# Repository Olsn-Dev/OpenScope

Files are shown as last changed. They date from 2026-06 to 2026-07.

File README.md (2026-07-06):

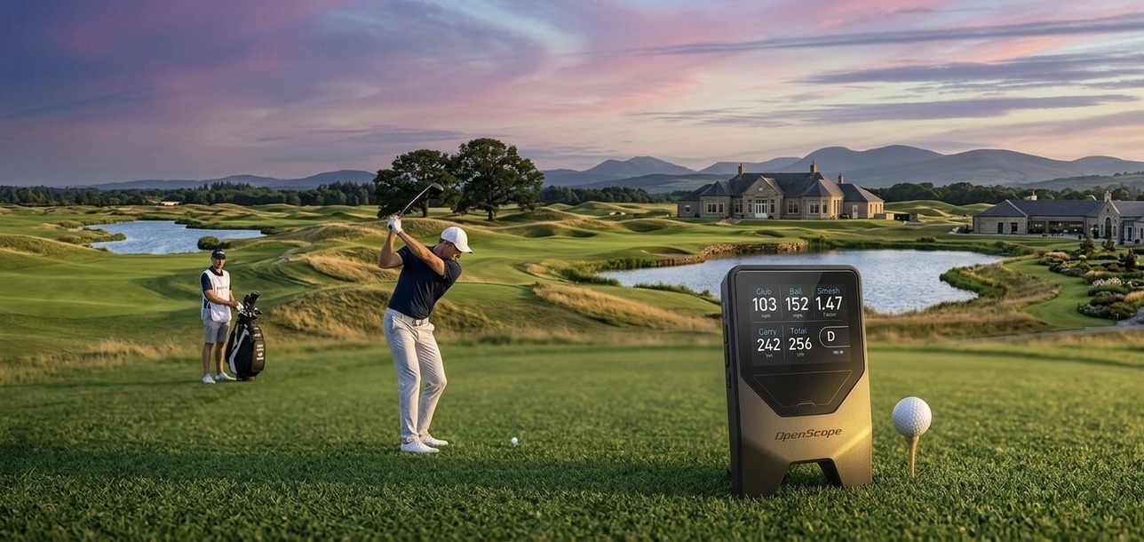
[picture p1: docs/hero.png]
OpenScope


# OpenScope — DIY Golf Launch Monitor

A radar-based golf launch monitor built around a **single** 24 GHz Doppler
radar module and an ESP32, modelled on the commercial single-Doppler
[Shot Scope LM1](https://shotscope.com/). Measures ball speed, club speed
and smash factor directly, and estimates carry and total distance.
Battery-powered, no phone required.

## What it measures (and what it can't)

A single Doppler sensor sees only speed along its line of sight. That is
enough for the core launch-monitor metrics, but **not** for launch angle,
spin, or shot direction — those need extra sensors. OpenScope is honest
about the difference:

| Metric | Source |
|---|---|
| Ball speed | **Measured** — post-impact Doppler peak |
| Club head speed | **Measured** — pre-impact clubhead Doppler peak |
| Smash factor | **Measured** — ball speed ÷ club speed |
| Carry distance | **Modeled** — from ball speed + per-club ballistic factor |
| Total distance | **Modeled** — carry + per-club rollout factor |
| Launch angle | **Not available** — needs a second/elevated sensor |
| Spin (back/side) | **Not available** — out of reach for plain Doppler |
| Side angle / dispersion | **Not available** — needs ≥2 sensors |

Other features:

- Units in km/h · m or mph · yds
- 3.5" color TFT display (ILI9488) + 3-button navigation
- Per-club statistics (avg, best carry) stored in flash
- Deep sleep with one-button wake
- Calibration mode with live FFT spectrum

## Technology

One **CDM324 24 GHz K-band Doppler radar** feeds into an LM358
preamplifier. The ESP32 samples the IF signal at 40 kHz and runs a
1024-point Hamming-windowed FFT (~25 ms window). Within that window the
spectrum can hold two peaks — the slower **clubhead** (pre-impact) and the
faster **ball** (post-impact):

```
CDM324 emits a continuous 24.125 GHz tone. A moving object Doppler-shifts
the reflection:

  f_d = 2 · v · f_c / c
  v [km/h] = f_d [Hz] × 0.022384

The unit sits in line with the shot, so the radar sees the true
line-of-sight speed — no angle correction is needed:

  ball speed  = (higher peak) × 0.022384 km/h
  club speed  = (lower  peak) × 0.022384 km/h
  smash       = ball speed ÷ club speed
  carry       = ball speed × club.carry_f      (modeled)
  total       = carry × (1 + club.roll_f)      (modeled)
```

## Project Phases

| Phase | Description | Status |
|---|---|---|
| 1 | Hardware & wiring | 🟡 In progress (v0.7) |
| 2 | Software & calibration | 🟡 In progress (v0.7) |
| 3 | Physical prototyping | 🔲 Not started |
| 4 | Housing & battery optimization | 🔲 Not started |
| 5 | Testing & validation | 🔲 Not started |

## Repository Structure

```
golf-launch-monitor/
├── src/
│   ├── config.h          # pins, FFT/Doppler constants, layout
│   ├── radar.cpp/.h      # ADC sampling, FFT, peak detection
│   ├── clubs.cpp/.h      # club table + per-club stats
│   ├── buttons.cpp/.h    # debounced 3-button input (UP / DOWN / OK)
│   ├── display.cpp/.h    # all TFT drawing, themes
│   ├── storage.cpp/.h    # NVS persistence
│   └── main.cpp          # button-driven UI state machine, sleep, main loop
├── test/
│   └── test_speed_from_fft/  # native smoke test (pio test -e native)
├── docs/
│   ├── bom.md            # Bill of materials with part numbers
│   ├── wiring.md         # Wiring diagram, radar placement
│   └── openscope-ui.png  # UI mockup
├── platformio.ini        # PlatformIO build configuration
└── README.md
```

## Quick Start

1. Order components — see [docs/bom.md](docs/bom.md)
2. Wire up the circuit — see [docs/wiring.md](docs/wiring.md)
3. Place the unit ~1.4 m behind the ball, facing the target (see below)
4. Install [PlatformIO](https://platformio.org/)
5. Clone this repo and open in VS Code
6. Build & upload: `pio run --target upload`
7. Calibrate — see below

## Radar Placement

Place the unit on the ground **~1.4 m (4–5 ft) behind the ball**, in line
with the hitting direction, with the sensor/screen facing the target —
the same geometry the Shot Scope LM1 uses. The ball flies *away* from the
unit; Doppler measures a receding object identically to an approaching one.

```
Top view:

 [Unit] ──── ~1.4 m ────► ●  →  →  →  target
  (on ground,            ball
   facing target)
```

- One CDM324 module, flat on the ground, boresight pointing at the target.
- Aim it down the intended shot line through the ball.
- Keep it static — vibration adds noise.

> **Speed-training tip:** to read swing speed alone, place the unit ~2.1 m
> behind the golfer instead.

## Controls

**Three buttons: UP, DOWN, OK.** UP/DOWN move the list highlight (auto-repeat
when held); OK activates the highlighted row. Holding **OK 1.5 s** powers off
from anywhere; pressing OK wakes the unit.

| Screen | UP / DOWN | OK |
|---|---|----|
| Main menu | Move highlight | Open **Start Session** / **Shot History** / **Settings** / **Shut Down** |
| Mode select | Move highlight | Open **Practice Range** / **On Course** / **Speed Training** / **Back** |
| Shot history | Page newer / older (last 50 shots) | Back |
| Session (Advanced) | Change club | Open the **session menu** |
| Session (Large Digit) | Cycle metric (club → ball → smash → carry → total) | Open the **session menu** |
| Session menu | Move highlight | **Resume** / **Change Club** / **Layout** / **Settings** / **End Session** |
| Result | Any button dismisses | Any button dismisses |
| Club picker | Move highlight (list follows) | Select club |
| Settings | Move highlight | Toggle / open the highlighted row |
| Calibration | Threshold **+10** / **−10** | **Save** + exit |

## Display Layout

Navigation is **Main menu → Mode select → Session**, modelled on the Shot
Scope LM1. A session shows shot data in one of two layouts (toggled in the
session menu or Settings), in either a **Black** (white labels) or **Blue**
(cyan labels) theme — both set in Settings.

### Advanced — 3×2 tile grid

```
┌──────────┬──────────┬──────────┐
│  CLUB    │  BALL    │  SMASH   │
│  98      │  152     │  1.55    │
│  km/h    │  km/h    │          │
├──────────┼──────────┼──────────┤
│  CARRY   │  TOTAL   │ ┌──────┐ │
│  187     │  209     │ │  7I  │ │  ← UP/DOWN change the club
│  m       │  m       │ └──────┘ │
├──────────┴──────────┴──────────┤
│ UP/DN: CLUB  SWING WHEN READY  OK: MENU │
└────────────────────────────────┘
```

The five tiles are the five single-Doppler metrics: **club speed**, **ball
speed**, **smash factor** (measured) plus **carry** and **total** (modeled).

- **Smash** tile turns green when a club peak was found; `--` (dimmed) if only
  the ball was detected, in which case Club and Smash both read `--`.

### Large Digit — one metric, full size

```
┌─────────────────────────────────┐
│         Total Distance          │
│                      ┌──────┐   │
│         209          │  7I  │   │
│          m           └──────┘   │
│                                 │
│ UP/DN: METRIC  SWING WHEN READY  OK: MENU │
└─────────────────────────────────┘
```

Toggle Advanced ⇄ Large Digit from the session menu (OK) or Settings; in
Large Digit, **UP/DOWN** cycle club speed → ball speed → smash → carry →
total.

### Speed Training

A single huge **swing-speed** number (the dominant Doppler peak) for swing-speed
practice — no club selection or distance modelling.

### Settings screen

Reached from the main menu, or via the session menu during a session.
UP/DOWN move the highlight; OK toggles or opens the highlighted row.

```
┌─────────────────────────────────────────────┐
│                 Settings     OK: toggle/open  │
├─────────────────────────────────────────────┤
│▌ Units                              Kmh/m   │
│▌ Color                              Black   │
│▌ Layout                          Advanced   │
│▌ Reset Stats                          7I    │
│▌ Clear History                         ►    │
│▌ Radar Cal.                            ►    │
│▌ Back                                  ◄    │
└─────────────────────────────────────────────┘
```

| Item | Action |
|---|---|
| Units | Toggle **Kmh/m** ↔ **Mph/Yds** |
| Color | **Black** ↔ **Blue** theme |
| Layout | **Advanced** ↔ **Large Digit** |
| Reset Stats | Clears avg/best for the active club |
| Clear History | Wipes the 50-shot log |
| Radar Cal. | Opens the detection-threshold calibration screen |
| Back | Save and return |

## Calibration

The detection threshold tells the firmware what signal level counts as
a real shot vs. background noise. It is saved to flash.

### Enter calibration

From the main menu → **Settings** → **Radar Cal.**

```
┌──────────────────────────────────────────────────────┐
│  CALIBRATION MODE         UP/DOWN: adjust   OK: save  │
├──────────────────────────────────────────────────────┤
│  [live FFT spectrum — teal bars below threshold,      │
│   red bars above — yellow line = threshold]           │
├───────────────┬───────────────┬──────────────────────┤
│ NOISE FLOOR   │ PEAK MAG      │ MAX SEEN             │
│ 14.2          │ 14.2          │ 14.2                 │
├───────────────┴───────────────┴──────────────────────┤
│ PEAK 0 Hz = 0.0 km/h                                  │
│ THRESHOLD 80         SUGGESTED 58                     │
├───────────────┬───────────────┬──────────────────────┤
│  DOWN: −10    │   OK: SAVE    │    UP: +10           │
└───────────────┴───────────────┴──────────────────────┘
```

### Steps

1. Leave the device still for ~30 s. Note **NOISE FLOOR** (typically 8–20).
2. Take a full practice swing. Note **MAX SEEN** (typically 200–600).
3. Press **DOWN** / **UP** (hold to sweep) to move the yellow threshold line
   between noise floor and MAX SEEN. The **SUGGESTED** value (`noise × 4`)
   is a good starting point.
4. Press **OK** to save and return.

| Measurement | Typical value |
|---|---|
| Noise floor | 10–20 |
| Shot peak | 200–600 |
| Good threshold | 60–100 |

> Raise the threshold if you get false triggers. Lower it if real shots
> are not detected.

## How it works

The ESP32 samples the radar IF at 40 kHz and runs a 1024-point Hamming FFT
(~25 ms window). Within each frame up to two peaks are searched, at least
`MIN_PEAK_SEP_HZ` apart: if their ratio looks like a plausible ball/club
pair, the **lower** frequency is the clubhead and the **higher** is the
ball; otherwise only ball speed is reported. Parabolic interpolation gives
sub-bin frequency accuracy. Each peak is converted to speed with
`HZ_TO_KMH`; smash is the ratio, and carry/total are modeled per club.

Because the unit is aligned with the shot line, the radar reads true
line-of-sight speed — there is no V-formation, no triangulation, and no
angle correction. See [the source](src/radar.cpp) for the signal chain and
[`test/`](test/) for a host-side smoke test of the speed-from-FFT path
(`pio test -e native`).

## UI Mockup

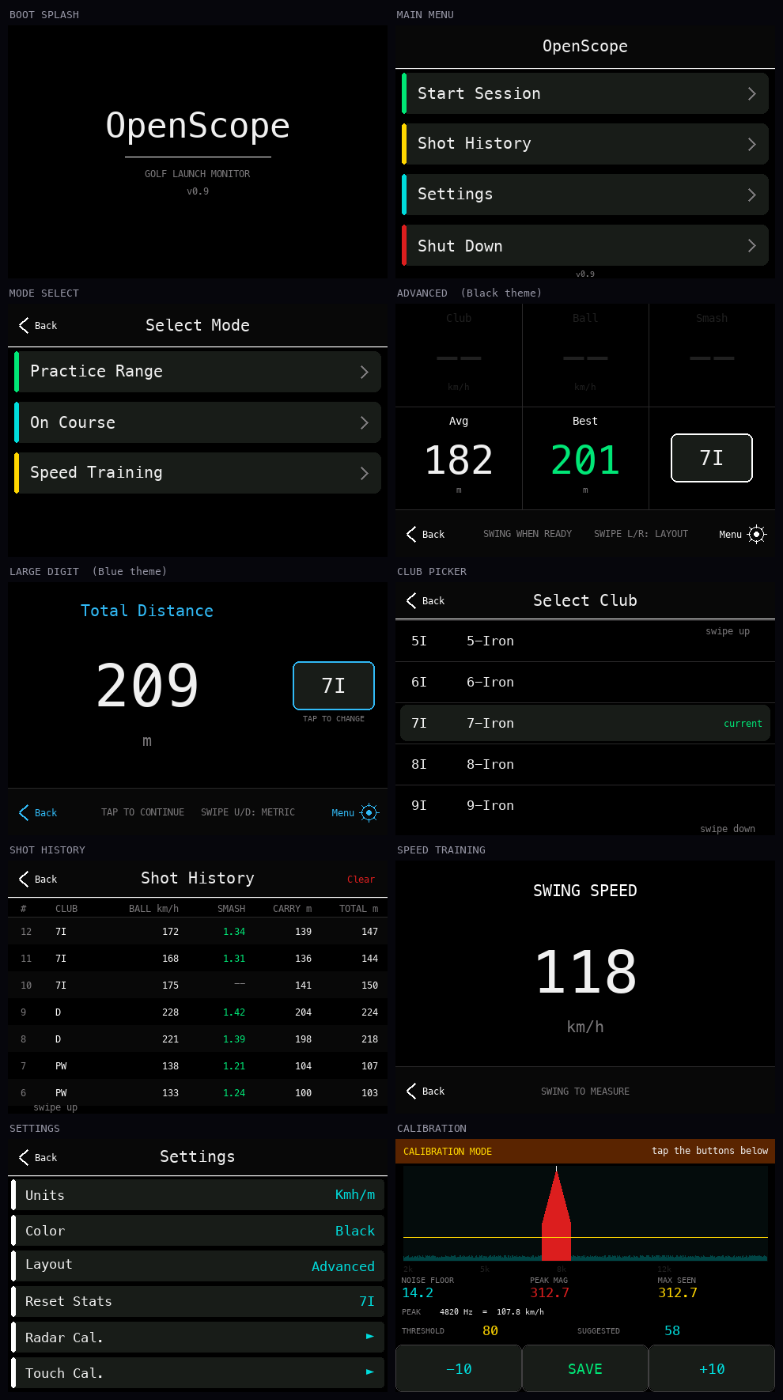
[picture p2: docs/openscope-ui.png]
OpenScope UI — ten screens: boot splash, menu, mode select, Advanced & Large Digit layouts, club picker, shot history, speed training, settings, calibration


## License

MIT

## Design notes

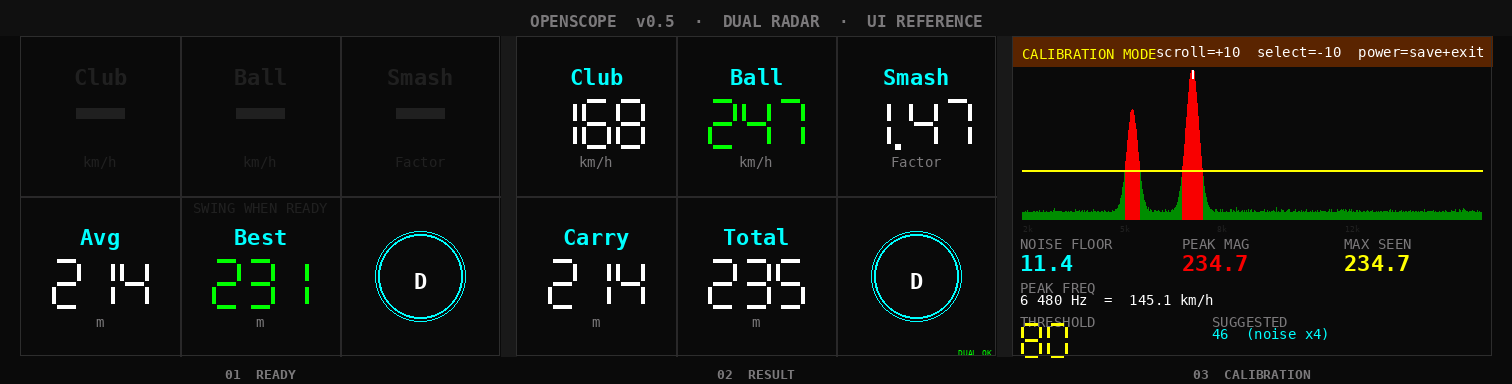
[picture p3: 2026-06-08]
docs/openscope-ui-dual.png

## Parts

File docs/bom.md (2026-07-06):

# Bill of Materials — OpenScope v0.8 (single radar)

All components from AliExpress unless noted. Prices approximate (SEK).

---

## Main Components

| # | Component | Search / Part number | Qty | ~Price (SEK) |
|---|---|---|-----|---|
| 1 | ESP32 dev board with 18650 battery holder | `ESP32 18650 battery holder board` | 1 | 160 |
| 2 | 18650 Li-Ion battery, 3000 mAh, protected | `18650 3000mAh protected battery` | 1 | 60 |
| 3 | CDM324 24 GHz Doppler radar module | AliExpress: `4000332661554` | 1 | 20 |
| 4 | LM358 preamp — bare DIP-8 IC **or** pre-built HW-164 ×100 module | `LM358 op amp DIP8` / `LM358 signal amplifier module` | 1 | 7 |
| 5 | 3.5" TFT display, SPI, ILI9488, 480×320 (touch panel not needed) | `3.5 inch SPI TFT ILI9488 480x320` | 1 | 120 |
| 6 | Tactile push button, 6×6 mm, PCB mount (UP / DOWN / OK) | `6x6mm tactile push button switch` | 4 | 8 |

Links to recomended parts:

[ESP32](https://www.aliexpress.com/item/1005007242909221.html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)

[CDM324](https://www.aliexpress.com/item/1005008401104531.html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)

[LM358](https://www.aliexpress.com/item/1005008965477359.html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)

[3.5" TFT DISPLAY](https://www.aliexpress.com/item/1005001999296476.html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)

---

## LM358 Preamplifier Passives

> **Skip this section if you use the pre-built HW-164 LM358 module** — it
> only needs its four pins wired (VCC/IN/OUT/GND) plus possibly a bias
> network; see `docs/wiring.md`.

A single radar needs a single preamp channel — one **LM358 IC** (the DIP-8
has two op-amps; use one, leave the other unused). The channel amplifies the
CDM324 IF signal ×100 and bandpass-filters it to 300 Hz – 16 kHz (covers
~7–360 km/h).

| Component | Value | Qty | Purpose |
|---|---|-----|---|
| Resistor | 1 kΩ | 1 | Gain lower resistor R1 |
| Resistor | 100 kΩ | 4 | R2 (feedback) + R3, R4 (bias divider) |
| Capacitor | 1 µF, film or electrolytic | 1 | AC coupling (high-pass ~160 Hz) |
| Capacitor | 100 pF, ceramic | 1 | Feedback cap (low-pass ~16 kHz) |
| Capacitor | 10 µF, electrolytic | 1 | Bias midpoint bypass |
| Capacitor | 100 nF, ceramic | 1 | VCC decoupling |

> All resistors 0.25 W, 5% tolerance or better. A mixed resistor/capacitor
> assortment kit from AliExpress (≈25 SEK) covers all values above.

---

## Wiring & Assembly

| Component | Search | Qty | ~Price (SEK) |
|---|---|-----|---|
| Dupont jumper wires, female–female, 20 cm | `dupont jumper wire female female` | 1 pack (40 pcs) | 15 |
| Dupont jumper wires, male–female, 20 cm | `dupont jumper wire male female` | 1 pack (40 pcs) | 15 |
| Perfboard / strip board, 5×7 cm | `perfboard prototype PCB 5x7` | 1 | 10 |
| USB-C or Micro-USB cable (matches your ESP32 board) | — | 1 | 20 |

---

## Cost Summary

| Category | ~Price (SEK) |
|---|---|
| Main components | ~370 |
| Preamp passives | 12 |
| Wiring & assembly | 60 |
| **Total** | **~440 SEK** |

---

## Notes

### Controls — three buttons
The firmware is driven by **three push buttons**:

| Button | GPIO | Function |
|---|---|---|
| UP | GPIO4 | Highlight up · previous club/metric · threshold +10 |
| DOWN | GPIO5 | Highlight down · next club/metric · threshold −10 |
| OK | GPIO2 | Select/confirm · hold 1.5 s → power off · press to wake (RTC-capable) |

Connect each button between its GPIO and GND — internal pull-ups, no
resistors. Order 4 buttons (3 used + 1 spare).

### Display
Buy the **ILI9488** 480×320 SPI variant. A touch panel is not required —
the firmware doesn't use it, so the cheaper non-touch module works (a touch
variant also works with its touch pins left unconnected).

### CDM324 radar (×1)
A single CDM324 module (GPIO1 via the preamp) sits on the ground ~1.4 m behind the ball,
facing the target. It measures ball and club speed directly; launch angle,
spin and dispersion are not measurable with one Doppler sensor and are not
faked. See `docs/wiring.md` for the placement diagram.

- The **standard CDM324** (not the -UK or -F variant) is approved for 24 GHz
  ISM use in Sweden and the EU. No licence required.
- Supply the CDM324 module from the board's `VCC5V` pin. **Note:** on the
  T-Energy-S3 that pin is only 5 V while USB is plugged in — on battery it
  carries raw battery voltage (3.7–4.2 V, no boost converter). Test radar
  range on battery; add an MT3608 boost module if it is poor.
- Do **not** connect the CDM324 IF pin directly to the ESP32 ADC — always via
  the LM358 preamp circuit.

### LM358 preamp bandwidth
The preamp must pass **300 Hz – 18 kHz** to cover the full speed range
(~7–400 km/h). A 5 kHz upper cutoff (common in older application notes) would
limit detection to ~112 km/h. Use the component values above.

### ESP32 + 18650 board
The linked board is the **LILYGO T-Energy-S3** (ESP32-S3-WROOM-1-N16R8:
16 MB flash, 8 MB PSRAM, USB-C). It has onboard HX6610S charging, an
IP3005A battery-protection chip and an SY8089 3.3 V buck — no separate
charging or protection circuit is needed. Charge via USB-C. There is **no
5 V boost converter**; see the CDM324 note above.

### Display backlight
The ILI9488 display's backlight (BL pin) can be connected directly to 3.3V for
always-on backlight. Do not connect it to 5V.

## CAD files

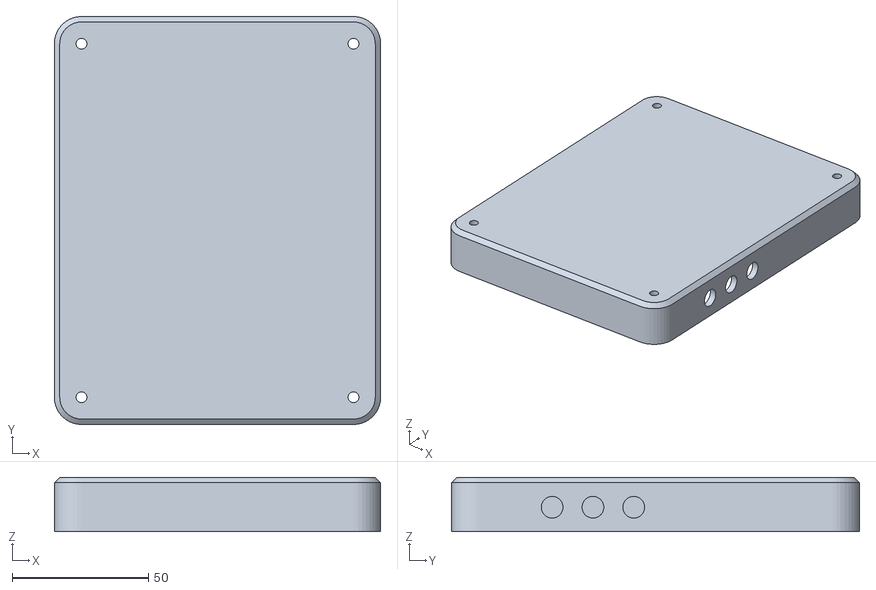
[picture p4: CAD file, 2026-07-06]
cad/BackShell-V2.STL
120.0 x 150.0 x 20.0

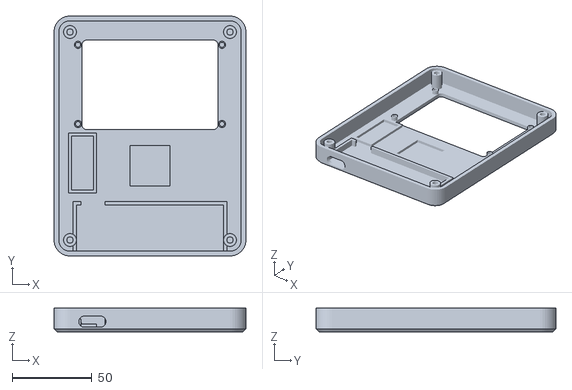
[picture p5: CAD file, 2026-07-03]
cad/FrontShell-V2.STL
120.0 x 150.0 x 15.0

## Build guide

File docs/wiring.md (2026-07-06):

# Wiring Guide

---

## System Overview

Target board: **LILYGO T-Energy-S3** (ESP32-S3-WROOM-1-N16R8, 18650 holder,
USB-C).

```
CDM324 (ground, 1.4 m behind ball) ──► LM358 preamp ──► GPIO1 (ADC1_CH0)
                                                           │
18650 battery ──► T-Energy-S3                              ├──► GPIO11/12/10/9/14 (SPI)
                  (onboard regulator)                      ├──► GPIO21 (backlight)
                                                           └──► ILI9488 TFT display

BTN_OK    ──► GPIO2 ──► GND   (select / confirm · hold = power off · wake)
BTN_UP    ──► GPIO4 ──► GND
BTN_DOWN  ──► GPIO5 ──► GND
```

> All navigation is via the three buttons: UP/DOWN move the highlight or
> change the club/metric, OK confirms. Holding OK ~1.5 s powers off.

> **ESP32-S3 pins to avoid** (used by the T-Energy-S3 board itself):
> IO0 (boot button), IO3 (battery-voltage divider), IO15/IO16 (32 kHz
> crystal), IO19/IO20 (USB-C data), IO35–IO37 (octal PSRAM), IO43/IO44
> (UART0), IO45/IO46 (boot straps).

---

## Radar Placement

Place the unit on the ground **~1.4 m (4–5 ft) behind the ball**, in line
with the hitting direction, sensor/screen facing the target — the same
geometry as the Shot Scope LM1. The ball flies *away* from the radar;
Doppler measures receding speed identically to approaching speed.

```
Top view:

 [Unit] ──── ~1.4 m ────► ●  →  →  →  target
  (on ground,            ball
   facing target)
```

**Key rules:**
- One CDM324, flat on the ground, boresight pointing at the target.
- Aim it down the intended shot line through the ball impact point.
- Keep it **static** — vibration adds noise.
- For **speed-training mode** (swing speed only), place it ~2.1 m behind
  the golfer instead.

> **Why a single radar?** A lone Doppler sensor measures speed along its
> boresight only. Aligned with the shot it reads true ball and club speed
> directly, but it cannot recover launch angle, spin, or side/dispersion —
> those need extra sensors and are intentionally not faked. See the metric
> table in the [README](../README.md).

---

## CDM324 Radar Pinout

| Pin | Connect to |
|-----|---|
| VCC | ESP32 board 5V rail |
| GND | GND |
| IF  | LM358 preamp input (via 1 µF coupling cap) |

---

## LM358 Preamplifier (×1)

### Option A — pre-built module (HW-164, what we use)

The blue **HW-164 "LM358 ×100 amplifier" module** (marked `2578-LM358` on the
back, four pins `VCC IN OUT GND`, blue gain trimmer) replaces the discrete
preamp below:

| Module pin | Connect to |
|---|---|
| VCC | 3.3V |
| IN  | CDM324 IF |
| OUT | GPIO1 (ADC1_CH0) |
| GND | GND |

- Start with the trimmer at max gain (~×100) and tune down if the ADC clips.
- **Check the idle level:** the firmware expects the output to idle near
  mid-rail (~2048 ADC counts). Use Settings → Radar Cal. to inspect it. If
  the output idles near 0 V instead, bias the module's IN pin to VCC/2 with
  two 100 kΩ resistors (one to 3.3V, one to GND) and feed the CDM324 IF in
  through a 1 µF series cap — same trick as R3/R4/C1 in the schematic below.

### Option B — discrete build (reference)

One **LM358 DIP-8** IC. The chip contains two op-amps; use one channel and
leave the second unused.

- **Gain:** ×100
- **Bandpass:** ~300 Hz – 16 kHz (covers 7–360 km/h Doppler range)
- **Output:** 0–3.3 V centred at 1.65 V (VCC/2)

```
LM358 DIP-8 pin-out (top view):
                ┌───────┐
  OUT A  (1) ───┤1     8├─── VCC (3.3 V)
   IN− A (2) ───┤2     7├─── OUT B  (unused)
   IN+ A (3) ───┤3     6├─── IN− B  (unused)
    GND  (4) ───┤4     5├─── IN+ B  (unused)
                └───────┘

LM358 channel A → GPIO1   (CDM324 IF)
```

**Single-channel schematic:**

```
           C1 (1µF)      R1 (1kΩ)
CDM324 IF ──┤├────────────┤├──────┬──── (+) IN
                                  │
                              R3 (100k)
                              to 3.3V         LM358 OUT ──► GPIO1

                              R4 (100k)   R2 (100kΩ)   C2 (100pF)
                              to GND    (−) IN ──┤├──────────┤├──┐
                                             │                    │
                                             └────────────────────┘
                                  │
                              C3 (10µF)
                              to GND

                 C4 (100nF) across VCC–GND near LM358
```

**How it works:**
- R3 + R4 bias the (+) input to 1.65 V (VCC/2). The firmware subtracts
  2048 from each ADC reading to centre it on zero.
- C1 + R1 set the high-pass corner: fc ≈ 1/(2π·1kΩ·1µF) ≈ 160 Hz
- C2 + R2 set the low-pass corner: fc ≈ 1/(2π·100kΩ·100pF) ≈ 16 kHz
- Gain = 1 + R2/R1 = 101 ≈ ×100

**Passives required (single channel):**

| Component | Value | Qty |
|---|---|-----|
| Resistor | 1 kΩ | 1 |
| Resistor | 100 kΩ | 4 |
| Capacitor | 1 µF | 1 |
| Capacitor | 100 pF | 1 |
| Capacitor | 10 µF | 1 |
| Capacitor | 100 nF | 1 (VCC decoupling) |

---

## TFT Display (ILI9488) → ESP32 SPI

Display only — the module's touch pins (`TCK / TCS / TDI / TDO / PEN`), if
present, are left unconnected.

| Module pin | ESP32-S3 GPIO | Notes |
|---|---|---|
| SDI (MOSI) | 11 | |
| SCK (SCLK) | 12 | |
| SDO (MISO) | 13 | optional — firmware never reads the panel |
| CS | 10 | display select |
| D/C | 9 | |
| RST | 14 | |
| BL (backlight) | 21 | GPIO-driven — firmware turns it off in deep sleep |
| VDD | 3.3V | |
| GND | GND | |

> IO9–14 all sit on the same T-Energy-S3 header (with a GND pin), so the
> whole display ribbon lands on one connector. IO10–13 are the S3's native
> FSPI pins — full 40 MHz SPI works.

---

## Control — three buttons

All navigation is on three momentary push buttons. One leg to the GPIO, the
other to GND — internal pull-ups, no resistors needed.

| Button | GPIO | Function |
|---|---|---|
| UP | GPIO4 | Move highlight up · previous club / metric · threshold +10 |
| DOWN | GPIO5 | Move highlight down · next club / metric · threshold −10 |
| OK | GPIO2 | Select / confirm · **hold 1.5 s → power off** · press to wake |

> GPIO2 is RTC-capable (on the ESP32-S3 every GPIO 0–21 is) — required for
> deep sleep wake. Do not move the OK button to a non-RTC pin (IO22+).
> UP/DOWN auto-repeat when held (fast scrolling / threshold sweeps).

**Button actions by screen:**

| Screen | UP / DOWN | OK |
|---|---|----|
| Main menu / Mode select | Move highlight | Open highlighted row |
| Session (Advanced) | Change club | Open session menu |
| Session (Large Digit) | Cycle focused metric | Open session menu |
| Session menu | Move highlight | Resume / Change Club / Layout / Settings / End Session |
| Result | — | Any button dismisses |
| Club picker | Move highlight (list follows) | Select club |
| Shot history | Page newer / older | Back |
| Settings | Move highlight | Toggle / open highlighted row |
| Calibration | Threshold +10 / −10 | Save + exit |

---

## Power

| Rail | Source | Used by |
|---|---|---|
| 3.3V | T-Energy-S3 buck (SY8089) | TFT VDD/BL, LM358 VCC |
| VCC5V | USB: ~5 V · battery: **3.7–4.2 V** (no boost!) | CDM324 VCC |
| GND | Common | All components |

> **⚠ CDM324 supply on battery:** the T-Energy-S3 has **no 5 V boost
> converter** — per the schematic its `VCC5V` header pin is USB VBUS when
> plugged in, but raw battery voltage (3.7–4.2 V) on battery power. The
> CDM324 is specced at 5 V ±0.25 V. Test it: many units still oscillate at
> ~4 V with reduced sensitivity, but if range is poor, add a small **MT3608
> boost module** (VBAT/VCC5V → 5 V, ~10 SEK) to feed the radar.

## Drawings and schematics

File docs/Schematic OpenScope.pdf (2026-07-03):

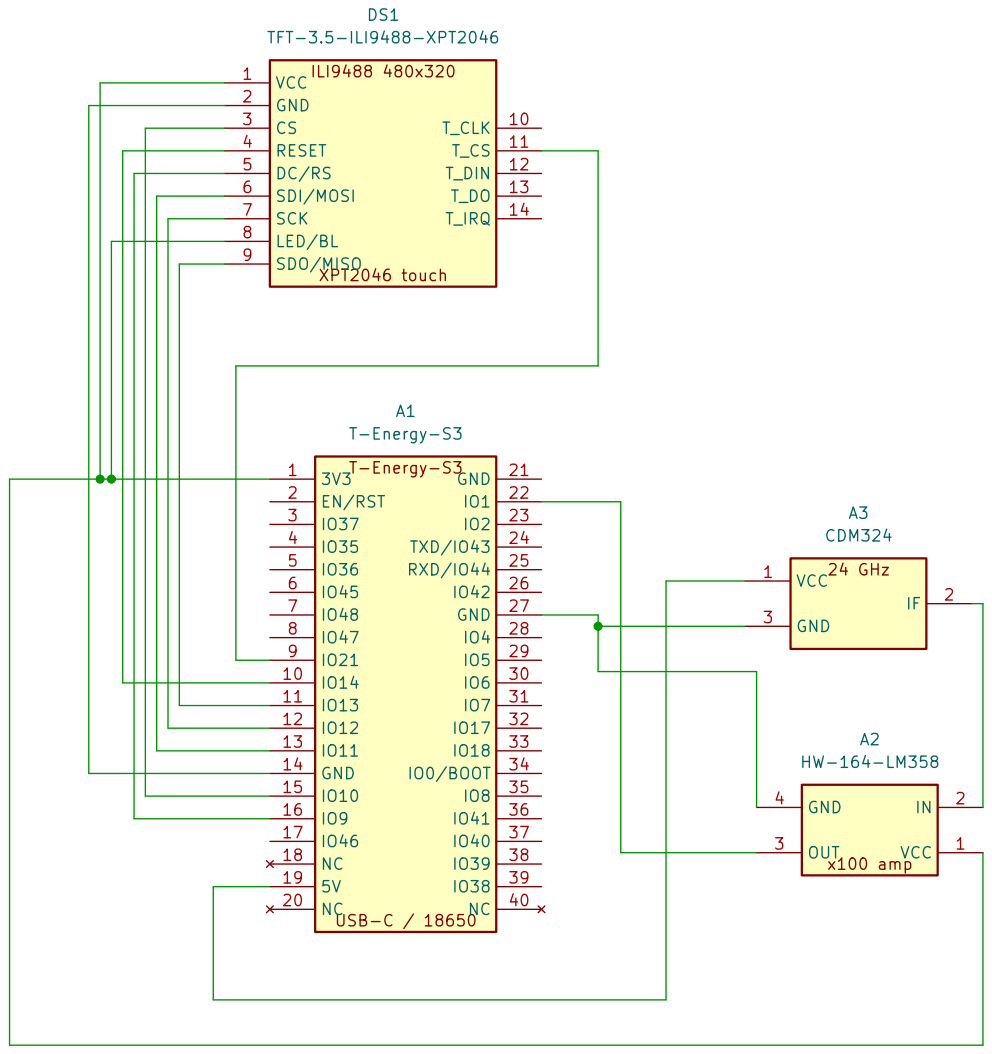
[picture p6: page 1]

Size: A4 | Rev: V 0.2
KiCad E.D.A. 10.0.4 | Id: 1/1

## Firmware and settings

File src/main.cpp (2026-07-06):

// OpenScope — DIY Golf Launch Monitor  v0.9
// ESP32 + 1× CDM324 24 GHz Doppler Radar + ILI9488 3.5" SPI TFT
//
// Source layout:
//   config.h   — all compile-time constants, pin definitions and UI enums
//   clubs.h/cpp— Club/ClubStats types and the CLUBS[] table
//   radar.h/cpp— ADC sampling, FFT, peak detection (single Doppler channel)
//   buttons.h/cpp — debounced 3-button input (UP / DOWN / OK)
//   display.h/cpp — all TFT drawing (owns TFT_eSPI object), themes
//   storage.h/cpp — NVS persistence (owns Preferences object)
//   main.cpp   — global state, the button-driven UI state machine, sleep
//
// UI model (LM1-style, driven by three buttons — UP, DOWN, OK):
//   Main menu ──► Mode select ──► Session (Advanced / Large Digit)
//             │              └──► Speed Training
//             └──► Shot History (last 50 shots, persisted in NVS)
//   • UP/DOWN move the list highlight; OK activates the highlighted row.
//   • In a session: UP/DOWN change club (Advanced) or cycle the focused
//     metric (Large Digit); OK opens the session menu (Resume / Change Club /
//     Layout / Settings / End Session).
//   • Holding OK ~1.5 s powers off from anywhere; pressing OK wakes the unit.

#include <Arduino.h>
#include "esp_sleep.h"
#include "driver/rtc_io.h"
#include "config.h"
#include "clubs.h"
#include "radar.h"
#include "buttons.h"
#include "display.h"
#include "storage.h"

// ─── Global state ─────────────────────────────────────────────────────────────

static ClubStats  g_stats[NUM_CLUBS];
static ShotRecord g_hist[HISTORY_MAX];
static int        g_hist_count = 0;
static int       g_club       = 0;
static float     g_threshold  = PEAK_THRESHOLD_DEFAULT;
static bool      g_use_mph    = false;
static bool      g_blue_theme = false;                 // false = Black theme
static int       g_layout     = LAYOUT_ADVANCED;       // session display layout
static UiMetric  g_metric     = MET_TOTAL;             // Large-Digit focus

// Top-level screen the loop() dispatcher is showing.
enum AppState { ST_MENU, ST_MODE };
static AppState g_state = ST_MENU;

// Persist every user-visible setting in one shot.
static void save_settings()
{
    nvs_save_settings(g_threshold, g_use_mph, g_club, g_blue_theme, g_layout);
}

// ─── Power off ────────────────────────────────────────────────────────────────
// Holding OK for BTN_LONG_MS anywhere powers the unit off; pressing OK wakes
// it (GPIO2 is RTC-capable, required for ext0 deep-sleep wake).

static void go_to_sleep()
{
    save_settings();
    display_goodbye();
    // The 3.3V rail stays powered in deep sleep, so the backlight must be
    // switched off explicitly — and held LOW through the sleep, since normal
    // GPIO output state is lost when the digital domain powers down.
    digitalWrite(PIN_TFT_BL, LOW);
    gpio_hold_en((gpio_num_t)PIN_TFT_BL);
    gpio_deep_sleep_hold_en();
    // The long-press event fires while OK is still held — wait for the release,
    // otherwise the low level would wake the chip right back up.
    while (digitalRead(PIN_BTN_OK) == LOW) delay(10);
    delay(50);
    // The normal GPIO pull-ups power down in deep sleep, which would leave the
    // wake pin floating (= random instant wake-ups). Enable the RTC-domain
    // pull-up, which stays active while ext0 wake is armed.
    rtc_gpio_pullup_en((gpio_num_t)PIN_BTN_OK);
    rtc_gpio_pulldown_dis((gpio_num_t)PIN_BTN_OK);
    esp_sleep_enable_ext0_wakeup((gpio_num_t)PIN_BTN_OK, 0);
    Serial.println("[PWR] Entering deep sleep");
    esp_deep_sleep_start();
}

// Poll the buttons, handling the global power-off hold. Never returns
// BTN_OK_LONG — that path ends in deep sleep.
static BtnEvent poll_ui()
{
    BtnEvent e = buttons_poll();
    if (e == BTN_OK_LONG) go_to_sleep();   // never returns
    return e;
}

// Move a list selection with UP/DOWN (no wrap). Returns true if it changed.
static bool move_sel(int& sel, BtnEvent e, int n_rows)
{
    const int prev = sel;
    if (e == BTN_UP)   sel = max(sel - 1, 0);
    if (e == BTN_DOWN) sel = min(sel + 1, n_rows - 1);
    return sel != prev;
}

// ─── Calibration loop ─────────────────────────────────────────────────────────
// UP/DOWN nudge the detection threshold (auto-repeat for fast sweeps);
// OK saves and exits.

static void calibration_loop()
{
    Serial.println("[CAL] Enter");
    ui_cal_header();

    float noise_ema = 0.0f, max_seen = 0.0f;
    bool  first  = true;
    const int bin_lo = (int)((double)MIN_DETECT_HZ / SAMPLE_RATE * FFT_SIZE);
    const int bin_hi = min((int)((double)MAX_DETECT_HZ / SAMPLE_RATE * FFT_SIZE),
                           FFT_SIZE/2 - 1);

    while (true) {
        switch (poll_ui()) {
            case BTN_DOWN:
                g_threshold = max(g_threshold - 10.0f, 5.0f);
                Serial.printf("[CAL] Threshold → %.0f\n", g_threshold);
                break;
            case BTN_UP:
                g_threshold = min(g_threshold + 10.0f, 2000.0f);
                Serial.printf("[CAL] Threshold → %.0f\n", g_threshold);
                break;
            case BTN_OK:
                save_settings();
                Serial.println("[CAL] Threshold saved, exit");
                return;
            default: break;
        }

        sample_radar();
        run_fft();

        // Find the highest peak in the detection window for the noise/peak metrics
        double peak_mag = 0.0;
        int    peak_bin = -1;
        for (int i = bin_lo; i <= bin_hi; i++) {
            if (vReal[i] > peak_mag) { peak_mag = vReal[i]; peak_bin = i; }
        }
        double peak_hz = (peak_bin >= 0)
                         ? ((double)peak_bin * SAMPLE_RATE / FFT_SIZE)
                         : 0.0;

        if (first) { noise_ema = (float)peak_mag; first = false; }
        else if (peak_mag < g_threshold)
            noise_ema = 0.92f * noise_ema + 0.08f * (float)peak_mag;

        if ((float)peak_mag > max_seen) max_seen = (float)peak_mag;

        ui_cal_update(vReal, peak_hz, peak_mag,
                      noise_ema, max_seen, g_threshold, g_use_mph);
    }
}

// ─── Settings loop ────────────────────────────────────────────────────────────
// Seven rows: Units, Color, Layout, Reset Stats, Clear History, Radar Cal.,
// Back. UP/DOWN move the highlight, OK activates the highlighted row.

static void settings_loop()
{
    int sel = 0;
    ui_set_theme(g_blue_theme);
    ui_settings_draw(g_club, g_use_mph, g_blue_theme, (UiLayout)g_layout, sel);

    while (true) {
        const BtnEvent e = poll_ui();
        const int prev = sel;

        if (move_sel(sel, e, SET_N_ROWS)) {
            ui_settings_select(prev, sel);
            continue;
        }
        if (e != BTN_OK) { delay(5); continue; }

        switch (sel) {
            case 0:  // Units (Mph/Yds ⇄ Kmh/m)
                g_use_mph = !g_use_mph;
                Serial.printf("[SET] Units → %s\n", speed_unit(g_use_mph));
                break;
            case 1:  // Color (Black ⇄ Blue)
                g_blue_theme = !g_blue_theme;
                ui_set_theme(g_blue_theme);
                Serial.printf("[SET] Theme → %s\n", g_blue_theme ? "Blue" : "Black");
                break;
            case 2:  // Layout (Advanced ⇄ Large Digit)
                g_layout = (g_layout == LAYOUT_ADVANCED)
                           ? LAYOUT_LARGE_DIGIT : LAYOUT_ADVANCED;
                Serial.printf("[SET] Layout → %s\n",
                              g_layout == LAYOUT_ADVANCED ? "Advanced" : "Large");
                break;
            case 3:  // Reset stats (current club)
                reset_stats(g_club, g_stats);
                ui_settings_draw(g_club, g_use_mph, g_blue_theme,
                                 (UiLayout)g_layout, sel, 3);
                delay(800);
                break;
            case 4:  // Clear shot history
                if (g_hist_count > 0) clear_history(g_hist, g_hist_count);
                ui_settings_draw(g_club, g_use_mph, g_blue_theme,
                                 (UiLayout)g_layout, sel, 4);
                delay(800);
                break;
            case 5:  // Radar calibration
                calibration_loop();
                break;
            case 6:  // Back / exit
                save_settings();
                Serial.println("[SET] Exit");
                return;
        }
        ui_settings_draw(g_club, g_use_mph, g_blue_theme, (UiLayout)g_layout, sel);
    }
}

// ─── Club picker ──────────────────────────────────────────────────────────────
// UP/DOWN move the highlight (the view scrolls to follow), OK selects the
// highlighted club. Selecting the current club leaves it unchanged.

static void club_picker()
{
    const int max_scroll = max(0, NUM_CLUBS - PICK_ROWS);
    int sel    = g_club;
    int scroll = constrain(sel - PICK_ROWS / 2, 0, max_scroll);
    ui_picker_draw(g_club, scroll, sel);

    while (true) {
        const BtnEvent e = poll_ui();
        const int prev = sel;

        if (move_sel(sel, e, NUM_CLUBS)) {
            // Keep the highlight on screen; page redraw only when it scrolls.
            int new_scroll = constrain(scroll, sel - PICK_ROWS + 1, sel);
            new_scroll = constrain(new_scroll, 0, max_scroll);
            if (new_scroll != scroll) {
                scroll = new_scroll;
                ui_picker_draw(g_club, scroll, sel);
            } else {
                ui_picker_select(prev, sel, scroll, g_club);
            }
            continue;
        }
        if (e == BTN_OK) {
            g_club = sel;
            save_settings();
            Serial.printf("[PICK] Club → %s\n", CLUBS[g_club].name);
            return;
        }
        delay(5);
    }
}

// ─── Shot history loop ────────────────────────────────────────────────────────
// Newest-first table of the persisted shot log. UP/DOWN page the list
// (UP = newer, DOWN = older); OK goes back. Clearing lives in Settings.

static void history_loop()
{
    int scroll = 0;
    ui_history_draw(g_hist, g_hist_count, scroll, g_use_mph);

    while (true) {
        const int max_scroll = max(0, g_hist_count - HIST_ROWS);
        switch (poll_ui()) {
            case BTN_DOWN:                               // reveal older shots
                if (scroll < max_scroll) {
                    scroll = min(scroll + (HIST_ROWS - 1), max_scroll);
                    ui_history_draw(g_hist, g_hist_count, scroll, g_use_mph);
                }
                break;
            case BTN_UP:                                 // reveal newer shots
                if (scroll > 0) {
                    scroll = max(scroll - (HIST_ROWS - 1), 0);
                    ui_history_draw(g_hist, g_hist_count, scroll, g_use_mph);
                }
                break;
            case BTN_OK:
                return;
            default:
                delay(5);
        }
    }
}

// ─── Session rendering helpers ────────────────────────────────────────────────

static void draw_ready()
{
    ui_set_theme(g_blue_theme);
    if (g_layout == LAYOUT_ADVANCED) ui_splash(g_club, g_stats, g_use_mph);
    else                             ui_large_ready(g_metric, g_club, g_use_mph);
}

static void draw_result(float ball_kmh, float club_kmh, float smash,
                        float carry_m, float total_m)
{
    ui_set_theme(g_blue_theme);
    if (g_layout == LAYOUT_ADVANCED)
        ui_result(ball_kmh, club_kmh, smash, carry_m, total_m, g_club, g_use_mph);
    else
        ui_large_result(g_metric, ball_kmh, club_kmh, smash,
                        carry_m, total_m, g_club, g_use_mph);
}

// ─── Session menu ─────────────────────────────────────────────────────────────
// Opened with OK during a session. Returns the chosen row:
//   0 Resume, 1 Change Club, 2 Layout toggle, 3 Settings, 4 End Session

static int session_menu()
{
    int sel = 0;
    ui_smenu_draw(sel, (UiLayout)g_layout);

    while (true) {
        const BtnEvent e = poll_ui();
        const int prev = sel;
        if (move_sel(sel, e, SMENU_N_ROWS)) { ui_smenu_select(prev, sel); continue; }
        if (e == BTN_OK) return sel;
        delay(5);
    }
}

// ─── Session loop (Practice / On Course) ──────────────────────────────────────
// Measures shots while staying responsive to the buttons. Returns when the
// user picks End Session in the session menu.

static void run_session(SessionMode /*mode*/)
{
    draw_ready();

    while (true) {
        // ── Buttons ──────────────────────────────────────────────────────────
        const BtnEvent e = poll_ui();

        if (e == BTN_UP || e == BTN_DOWN) {
            if (g_layout == LAYOUT_ADVANCED) {           // change club
                g_club = (g_club + (e == BTN_UP ? NUM_CLUBS - 1 : 1)) % NUM_CLUBS;
                save_settings();
            } else {                                     // cycle focused metric
                g_metric = (e == BTN_DOWN)
                           ? (UiMetric)((g_metric + 1) % MET_COUNT)
                           : (UiMetric)((g_metric + MET_COUNT - 1) % MET_COUNT);
            }
            draw_ready();
            continue;
        }
        if (e == BTN_OK) {
            switch (session_menu()) {
                case 1: club_picker();  break;
                case 2:                                   // toggle layout
                    g_layout = (g_layout == LAYOUT_ADVANCED)
                               ? LAYOUT_LARGE_DIGIT : LAYOUT_ADVANCED;
                    save_settings();
                    break;
                case 3: settings_loop(); break;
                case 4: return;                           // End Session
                default: break;                           // 0 = Resume
            }
            draw_ready();
            continue;
        }

        // ── Radar detection ──────────────────────────────────────────────────
        sample_radar();
        double ball_hz = 0.0, club_hz = 0.0;
        if (!detect_speeds(ball_hz, club_hz, g_threshold)) continue;

        // ── Physics ───────────────────────────────────────────────────────────
        // MEASURED: ball/club speed off the Doppler shift. MODELED: carry/total
        // from each club's empirical carry+roll factors (a single Doppler can't
        // measure launch angle, so distances are a model, not a per-shot reading).
        const float ball_kmh = (float)(ball_hz * HZ_TO_KMH);
        const float club_kmh = (club_hz > 0.0) ? (float)(club_hz * HZ_TO_KMH) : 0.0f;
        const float smash    = (club_kmh > 0.0f) ? (ball_kmh / club_kmh) : 0.0f;
        const float carry_m  = ball_kmh * CLUBS[g_club].carry_f;
        const float total_m  = carry_m * (1.0f + CLUBS[g_club].roll_f);

        Serial.printf("[HIT] Ball %.1f km/h | Club %.1f km/h | Smash %.2f"
                      " | Carry %.0f m | Total %.0f m\n",
                      ball_kmh, club_kmh, smash, carry_m, total_m);

        record_carry(g_club, carry_m, g_stats);
        record_shot({ (uint8_t)g_club, ball_kmh, club_kmh, carry_m, total_m },
                    g_hist, g_hist_count);
        draw_result(ball_kmh, club_kmh, smash, carry_m, total_m);

        // Hold the result; any button dismisses early, else auto-return at 6 s.
        uint32_t t0 = millis();
        while (millis() - t0 < 6000) {
            if (poll_ui() != BTN_NONE) break;
            delay(20);
        }
        draw_ready();
    }
}

// ─── Speed Training loop ──────────────────────────────────────────────────────
// One big swing-speed number (the dominant Doppler peak). OK goes back.

static void speed_loop()
{
    ui_set_theme(g_blue_theme);
    ui_speed(0.0f, g_use_mph, false);

    while (true) {
        if (poll_ui() == BTN_OK) return;

        sample_radar();
        double ball_hz = 0.0, club_hz = 0.0;
        if (!detect_speeds(ball_hz, club_hz, g_threshold)) continue;

        const float kmh = (float)(ball_hz * HZ_TO_KMH);          // dominant peak
        Serial.printf("[SPEED] %.1f km/h\n", kmh);
        ui_speed(kmh, g_use_mph, true);

        uint32_t t0 = millis();
        while (millis() - t0 < 4000) {
            if (poll_ui() != BTN_NONE) break;
            delay(20);
        }
        ui_speed(0.0f, g_use_mph, false);
    }
}

// ─── Blocking menu helpers ────────────────────────────────────────────────────

// Run the main-menu selection. Returns the activated row 0..3.
static int menu_wait()
{
    int sel = 0;
    ui_menu_draw(sel);
    while (true) {
        const BtnEvent e = poll_ui();
        const int prev = sel;
        if (move_sel(sel, e, 4)) { ui_menu_select(prev, sel); continue; }
        if (e == BTN_OK) return sel;
        delay(5);
    }
}

// Run the mode-select screen. Returns 0/1/2 (mode) or -1 for Back.
static int mode_wait()
{
    int sel = 0;
    ui_mode_draw(sel);
    while (true) {
        const BtnEvent e = poll_ui();
        const int prev = sel;
        if (move_sel(sel, e, 4)) { ui_mode_select(prev, sel); continue; }
        if (e == BTN_OK) return (sel == 3) ? -1 : sel;
        delay(5);
    }
}

// ─── Arduino entry points ─────────────────────────────────────────────────────

void setup()
{
    Serial.begin(115200);
    Serial.println("\n[OpenScope] " FW_VERSION " booting");

    // After a deep-sleep wake the OK pad is still claimed by the RTC mux
    // (go_to_sleep enables its RTC pull-up); hand it back to the digital GPIO
    // matrix before buttons_init() configures it. The backlight hold from
    // go_to_sleep must be released too, or display_init can't switch it on.
    rtc_gpio_deinit((gpio_num_t)PIN_BTN_OK);
    gpio_deep_sleep_hold_dis();
    gpio_hold_dis((gpio_num_t)PIN_TFT_BL);
    buttons_init();

    // ADC: 12-bit, 11 dB attenuation → ~0–3.1 V input range
    analogReadResolution(12);
    analogSetPinAttenuation(RADAR_ADC_PIN, ADC_11db);

    nvs_load(g_threshold, g_use_mph, g_club, g_blue_theme, g_layout,
             g_stats, NUM_CLUBS);
    nvs_load_history(g_hist, g_hist_count);
    Serial.printf("[NVS] Shot history: %d shot(s)\n", g_hist_count);
    display_init();
    ui_set_theme(g_blue_theme);
    display_splash();

    g_state = ST_MENU;
    Serial.printf("[OpenScope] Club: %s  Units: %s  Theme: %s  Layout: %s\n",
                  CLUBS[g_club].name, speed_unit(g_use_mph),
                  g_blue_theme ? "Blue" : "Black",
                  g_layout == LAYOUT_ADVANCED ? "Advanced" : "Large");
    Serial.println("[OpenScope] Ready.");
}

void loop()
{
    switch (g_state) {
        case ST_MENU:
            switch (menu_wait()) {
                case 0: g_state = ST_MODE; break;        // Start Session
                case 1: history_loop();    break;        // Shot History
                case 2: settings_loop();   break;        // Settings
                case 3: go_to_sleep();     break;        // Shut Down
            }
            break;

        case ST_MODE:
            switch (mode_wait()) {
                case -1: g_state = ST_MENU;            break;   // Back
                case MODE_SPEED: speed_loop();          break;
                case MODE_PRACTICE:
                case MODE_ONCOURSE:
                    run_session((SessionMode)MODE_PRACTICE);
                    break;
            }
            break;
    }
}

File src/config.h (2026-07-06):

#pragma once

#define FW_VERSION "v0.9"

// ─── Pins ─────────────────────────────────────────────────────────────────────

// Single-radar layout:
//   One CDM324 Doppler module on the ground, ~1.4 m behind the ball, in line
//   with the hitting direction and facing the target (same geometry as the
//   Shot Scope LM1). The ball recedes from the unit; Doppler measures receding
//   speed identically to approaching speed.
//
// Target board: LILYGO T-Energy-S3 (ESP32-S3). On the S3, ADC1 lives on
// GPIO1–10 and every GPIO 0–21 is RTC-capable. Board-reserved pins to avoid:
// IO0 (boot btn), IO3 (battery divider), IO15/16 (32 kHz crystal),
// IO19/20 (USB), IO35–37 (octal PSRAM), IO43/44 (UART0), IO45/46 (straps).
#define RADAR_ADC_PIN    1    // CDM324 IF → LM358 preamp → ADC1_CH0

// Navigation is three physical buttons, each GPIO → GND (internal pull-ups).
// OK doubles as the power button: short press = select, hold = power off,
// press = wake from deep sleep (GPIO2 is RTC-capable — ext0 wake).
#define PIN_BTN_OK       2    // select / confirm; hold = power off; wake pin
#define PIN_BTN_UP       4
#define PIN_BTN_DOWN     5

// Display backlight (module BL/LED pin). GPIO-driven — not tied to 3.3V — so
// power-off can actually turn the backlight off; it is held LOW through deep
// sleep via gpio_hold. GPIO21 sits on the same header as the display SPI pins.
#define PIN_TFT_BL      21

// Button timing (see buttons.cpp).
#define BTN_DEBOUNCE_MS       25
#define BTN_LONG_MS         1500   // OK hold → power off
#define BTN_REPEAT_DELAY_MS  450   // UP/DOWN auto-repeat after this hold…
#define BTN_REPEAT_MS        140   // …then one event per this interval

// ─── Sampling & FFT ───────────────────────────────────────────────────────────

#define SAMPLE_RATE  40000   // Hz — Nyquist covers 20 kHz (~447 km/h)
#define FFT_SIZE     1024    // bins → 39 Hz/bin ≈ 0.87 km/h resolution

// ─── Doppler physics (CDM324, f_c = 24.125 GHz) ───────────────────────────────

#define HZ_TO_KMH  0.022384f   // km/h per Doppler Hz
#define HZ_TO_MPH  0.013912f

// ─── Detection ────────────────────────────────────────────────────────────────

#define MIN_DETECT_HZ           1800    // ~40 km/h
#define MAX_DETECT_HZ          16000    // ~358 km/h
#define PEAK_THRESHOLD_DEFAULT  80.0f
#define SMASH_MIN_RATIO         1.15f   // ball/club Hz ratio floor for a valid pair
#define MIN_PEAK_SEP_HZ          800    // minimum Hz gap between two peaks

// ─── Display ──────────────────────────────────────────────────────────────────

#define TFT_ROTATION  1         // landscape, USB connector on right
#define SCR_W  480
#define SCR_H      320
#define COL_W      (SCR_W / 3)
#define ROW_H      130   // main tile row height (2×130 + 60 = 320)
#define MINI_ROW_H  60   // mini row at bottom (tap-to-continue hint)

// RGB565 colour palette
#define COL_DIV      0x2945   // dark teal — grid divider lines
#define COL_UNIT     0x7BCF   // mid-grey  — unit labels
#define COL_DIM      0x2104   // near-black — inactive / dimmed tiles
#define COL_CAL_HDR  0x5920   // dark green — calibration header bar
#define COL_SEL_BG   0x1082   // very dark blue — settings selection bg
#define COL_BTN_BG   0x18E3   // dark slate — list-row / button-bar fill
#define COL_BTN_BRD  0x4208   // grey       — button-bar border
#define COL_TILE_BG  0x0841   // very dark grey — card tile background
#define BTN_RADIUS   8        // rounded corner radius for buttons/rows

// ─── Themes (LM1-style) ───────────────────────────────────────────────────────
// Two selectable themes share the same layout; only the metric-label colour
// changes. Background is always black; numbers are white; units grey.
//   Black theme  → labels white
//   Blue theme   → labels cyan
#define COL_LABEL_BLACK  0xFFFF   // white — label colour in the black theme
#define COL_LABEL_BLUE   0x35DE   // ~#36B6F0 cyan — label colour in the blue theme

// ─── UI enums ─────────────────────────────────────────────────────────────────
// On-device display layout for a session (toggled in the session menu or
// Settings).
enum UiLayout { LAYOUT_ADVANCED = 0, LAYOUT_LARGE_DIGIT = 1 };

// The five LM1 metrics, in the order the Large-Digit screen cycles through them.
enum UiMetric {
    MET_CLUB = 0, MET_BALL, MET_SMASH, MET_CARRY, MET_TOTAL, MET_COUNT
};

// Session mode chosen from the mode-select screen. On Course currently behaves
// like Practice (both feed the shared shot-history log); Speed only shows
// swing speed and is not logged (no club context).
enum SessionMode { MODE_PRACTICE = 0, MODE_ONCOURSE, MODE_SPEED };

// ─── Screen layout ────────────────────────────────────────────────────────────
// Geometry used by the draw code (display.cpp).
// A "bar" is a full-width hint strip at the bottom of a screen.

#define BAR_H        60                  // bottom action-bar height
#define BAR_Y        (SCR_H - BAR_H)     // 260 — top edge of bottom bars
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

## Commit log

2026-06-04 feat: v0.2 — club selection, full shot metrics, persistent stats
    - Two-peak FFT detection separates club speed and ball speed
    - Smash factor, carry and total distance per club (14 clubs)
    - Club selection via GPIO0 button (short=next, long=reset stats)
    - Per-club avg/max/min carry stored in NVS (survives reboot)
    - Result screen: ball speed, club speed, smash, carry, total
    - Splash screen: current club + its stats always visible
    - Replaced blocking delay() with millis() loop (button-responsive)
    [main.cpp]
2026-06-04 feat: v0.3 — calibration mode with live FFT spectrum
    - Hold button 3s to enter calibration mode
    - Live spectrum display across detection window (1.8–16 kHz)
    - Threshold shown as adjustable yellow line on spectrum
    - Short press = +10, medium press = -10, long 3s = save to NVS
    - Tracks noise floor (EMA) and max seen; suggests threshold = noise×4
    - g_threshold loaded from NVS at boot — no recompile needed
    [main.cpp]
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2026-06-04 feat: v0.4 — tile-grid UI, mph/km/h toggle, settings menu
    - New 3×2 tile-grid layout matching Shot Scope LM1 reference
    - Font 7 (7-segment) for numbers, font 4 for labels, font 2 for units
    - Club abbreviation circle (D, 3W, 5I, PW...) in bottom-right tile
    - Settings menu (medium press): toggle km/h ↔ mph, reset stats, calibration
    - Units saved to NVS — survives reboot
    - mph mode: speeds in mph, distances in yards
    - Updated button scheme: short=club, medium=settings, long=calibration
    - Added UI reference mockup and design philosophy to docs/
    [main.cpp]
2026-06-04 docs: complete BOM and wiring guide
    BOM:
    - Add tactile button (6x6mm) as explicit line item
    - Specify all LM358 preamp passives with exact values (1kΩ, 100kΩ, 1µF, 100pF, 10µF, 100nF)
    - Add wiring/assembly section (Dupont wires, perfboard, USB cable)
    - Add cost summary table
    - Fix bandpass note: 300 Hz–18 kHz, not 5 kHz (5 kHz only covers ~112 km/h)
    Wiring:
    - Add ASCII schematic for LM358 preamp with component labels
    - Explain gain, high-pass and low-pass corner frequencies
    - Add button wiring table with GPIO0 + GND
    - Add button function reference table (v0.4 scheme)
    - Add voltage rail summary
2026-06-05 feat: v0.5 — three dedicated buttons + deep sleep
    Hardware:
    - GPIO25 SCROLL: navigate / +10 in calibration
    - GPIO26 SELECT: confirm / -10 in calibration
    - GPIO27 POWER: hold 2s → deep sleep; RTC GPIO wakes device
    Firmware:
    - Remove single-button duration scheme; each button does one clear thing
    - scroll_pressed() / select_pressed(): debounced falling-edge detection
    - power_held(ms): blocking hold timer, ignores short taps
    - go_to_sleep(): saves NVS, shows "Goodbye", enters esp_deep_sleep
    - Club selection now saved to NVS so it persists across power cycles
    - Result screen: Select dismisses early, Scroll changes club
    Docs:
    - BOM: 4 tactile buttons (3 used + spare), updated note with GPI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
    [main.cpp]
2026-06-07 Add dual-radar support with cross-validation (GPIO34 + GPIO35)
    Two CDM324 modules mounted 30 mm apart are now sampled sequentially.
    Both FFTs run each frame; get_peaks_from_buf() extracts speeds from
    each buffer independently. detect_speeds() cross-validates the two
    ball-Hz readings: if they agree within 10 % the values are averaged
    (confidence=2, DUAL OK); if one radar is silent the other is used alone
    (confidence=1, SINGLE); if both fire but disagree by >10 % the frame
    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
2026-06-07 Update UI reference image: Ready / Result / Calibration layout
    Matches original 3-panel format. Result panel shows dual-radar changes:
    ball speed in green when both radars agree, DUAL OK badge bottom-right.
2026-06-07 Replace UI reference image with accurate 480x320 per-panel render
    Each panel now matches the actual screen resolution (480x320).
    Big numbers use a proper 7-segment digit renderer (matching TFT_eSPI
    font 7). Y-coordinates, datums and colours are taken directly from
    the firmware source. Panels: Ready / Result (DUAL OK) / Calibration.
2026-06-08 Fix three bugs: interleaved radar sampling, dual mismatch fallback, calibration threshold line
    - sample_radar(): sample both channels inside the same 25µs period so
    vReal[i] and vRealB[i] capture the same moment; previously the two
    buffers were 25 ms apart, making dual cross-validation useless.
    - detect_speeds(): on DUAL_AGREE_PCT mismatch fall back to radar A
    (confidence=1) instead of returning false; a spurious B reflection
    no longer silently discards a confirmed A hit.
    - ui_cal_update(): clamp threshold line to CAL_SPEC_Y so it is always
    visible even before the first swing, when max_seen ≈ 0.
    [main.cpp]
2026-06-08 v0.6: dual-radar launch angle measurement
    Replace cross-validation logic with physics-based launch angle
    computation using two CDM324 radars at different elevation angles.
    Firmware (src/main.cpp):
    - Add RADAR_B_ANGLE_DEG (20°), DEG_TO_RAD, LAUNCH_MIN/MAX_DEG
    - Add typ_launch field to Club struct for carry angle correction
    - Add compute_launch_angle(): binary search on f_A/f_B ratio to solve
    cos(α)/cos(α−θ) = ratio with 40 iterations (~0.05° accuracy)
    - detect_speeds() now returns launch_deg via reference
    - Carry uses measured launch angle: speed corrected by 1/cos(α),
    distance scaled by sin(2α)/sin(2α_typical) × carry_f
    - Falls back to empirical carry_f when launch angle unav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
    [main.cpp]
2026-06-08 Refactor: split monolithic main.cpp into six modules
    src/config.h — all compile-time constants and pin #defines
    src/clubs.h/cpp — Club/ClubStats types and CLUBS[] table
    src/radar.h/cpp — ADC sampling, FFT, peak detection, launch angle solver
    src/display.h/cpp — all TFT drawing; owns TFT_eSPI object
    src/storage.h/cpp — NVS load/save; owns Preferences object
    src/main.cpp — global state, buttons, sleep, loops, setup/loop
    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
2026-06-08 Add mockup generator script; update UI image for v0.6
    tools/generate_mockup.py: Python script that reads layout constants and
    colors directly from src/config.h and renders all three screens (Ready,
    Result, Calibration) to docs/openscope-ui.png. Run from repo root with
    python tools/generate_mockup.py
    docs/openscope-ui.png: regenerated — now shows the v0.6 tile layout:
    Club | Ball | Launch (top row)
    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
2026-06-09 Add Settings screen to UI mockup; update README layout docs
    - generate_mockup.py now renders four screens in a 2×2 grid:
    Ready, Result, Settings, Calibration
    - README hero image switched from stale GitHub attachment to
    docs/openscope-ui.png (relative path, always in sync)
    - Display Layout section expanded with Settings screen ASCII art
    and controls table
2026-06-09 Update UI mockup to 2×2 four-screen layout; fix README hero image
    Replaces broken GitHub attachment URL with relative path to
    docs/openscope-ui.png. Mockup now shows Ready, Result, Settings,
    and Calibration screens side by side.
2026-06-09 Add 3-radar V-formation for side angle and launch angle measurement
    Replace 2-radar system with 3 radars:
    - Radar L + R: ground-level V-formation (RADAR_V_HALF_DEG default 75°,
    matching a 150° total V-angle with tip toward target)
    - Radar T: top-mounted, tilted upward for launch angle (GPIO 32)
    Side angle is solved analytically from f_L/f_R = cos(β−V)/cos(β+V)
    via binary search. Launch angle uses the exact 3D formula:
    F = (f_L + f_R) / (2·cos(β)·cos(V)) [horizontal speed proxy]
    tan(α) = (f_T/F − cos(β)·cos(θ_T)) / sin(θ_T)
    True ball speed k is fully corrected for both angles before conversion.
    Display: side angle shown bottom-left as "R 2.3°" / "L 2.3°" / "STRAIGH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
    [config.h, main.cpp]
2026-06-09 Optimise V-angle to 45° for maximum side-angle accuracy
    45° per arm (90° total V at vertex) maximises sin(V)·cos(V),
    giving the best balance of signal strength and angular sensitivity.
    Estimated resolution < 0.1° at 150 km/h ball speed.
    Also tighten SIDE_MAX_DEG to ±10° (covers all realistic golf shots).
    [config.h]
2026-06-09 Set V-angle to 150° (75° per arm) as requested
    Matches the physical sketch: obtuse V with 150° at the vertex.
    Valid side-angle range ±13° (limit is 90°−75° = 15°).
2026-06-09 Revert to 45° V-angle (90° total) for optimal CDM324 performance
    [config.h]
2026-06-09 Update all documentation for 3-radar V-formation system
    - README: new technology section with 3-radar math, updated mounting
    diagrams (V-formation top view + top radar side view), updated
    display layout showing side angle
    - wiring.md: new system overview with 3 channels, full V-formation
    mounting guide, dual LM358 IC note, updated power table
    - bom.md: CDM324 qty 2→3, LM358 qty 1→2, updated passives for 3
    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
2026-06-09 Switch preamp from 2× LM358 to 1× LM324 quad op-amp
    LM324 (DIP-14, 4 channels) replaces two LM358s — one IC covers all
    three radar channels with one channel to spare.
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2026-06-09 Fix placement: unit goes behind golfer, not at tee
    0.5–1 m behind the golfer (like Trackman/FlightScope), pointing toward
    target. Ball flies away from radar — Doppler is identical either way.
    Updated wiring.md and README diagrams.
2026-06-10 Convert UI to touchscreen with single power button
    Switch from 3 physical buttons to a touch-driven UI, keeping only the
    Power button (GPIO27). Display driver changes ST7796 -> ILI9488 to match
    the touch-capable panel; MISO is now wired (GPIO19, required for XPT2046
    readback) with TOUCH_CS on GPIO21.
    - display.cpp: touch layer (ui_get_tap + per-screen hit-tests), on-screen
    buttons, redesigned splash/result/settings/calibration for touch
    - main.cpp: tap-driven navigation, removed scroll/select handling
    - storage: persist 5-value XPT2046 calibration in NVS; 4-corner cal on
    first boot or via Settings -> Touch Cal.
    - config/platformio: ILI9488 driver, touch flags, touch layout constants
    - d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
    [config.h, main.cpp]
2026-06-10 Update mockup generator and image for touchscreen UI
    Render touch-driven screens: SETTINGS bar on Ready, tap-to-continue on
    Result, tappable item rows + DONE bar on Settings, and [-10]/[SAVE]/[+10]
    buttons on Calibration. Layout constants fall back to firmware defaults
    so the generator still runs against the button-based config.h on main.
2026-06-10 Redesign UI with rounded corners and polished visuals
    - Buttons (SETTINGS, DONE, cal buttons) now use fillRoundRect/drawRoundRect
    with BTN_RADIUS=8 for a modern pill-like look
    - Club circle gets a filled dark background (COL_BTN_BG) before drawing the
    double-thick cyan border, giving it depth
    - Settings rows use rounded card strips with a thicker (6px) left accent stripe
    - Add COL_TILE_BG and BTN_RADIUS constants to config.h
    - Mockup generator mirrors all changes via Pillow rounded_rectangle with fallback
    [config.h]
2026-06-11 Refactor firmware to a single Doppler radar
    Strip the 3-radar (L/R/T V-formation) triangulation down to one CDM324
    channel, matching the Shot Scope LM1 geometry (one sensor 1.4 m behind
    the ball, facing the target).
    - config.h: one RADAR_ADC_PIN; remove V/T geometry and launch/side limits.
    - radar.cpp/.h: single FFT buffer + instance, one ADC channel; delete the
    compute_side_angle/compute_launch_angle solvers. detect_speeds() now
    returns just ball_hz/club_hz.
    - main.cpp: single ADC pin; carry modeled from ball speed only (no launch
    correction); drop launch/side from logs and the UI call.
    - display.cpp/.h: result/ready grid now shows the five single-Doppler
    metrics (Club, Ball, Smash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
    [config.h, main.cpp]
2026-06-11 Update docs + mockup for the single-radar design
    - README: rewrite to one CDM324 placed ~1.4 m behind the ball facing the
    target; add a measured/modeled/unavailable metric table; result grid now
    Club/Ball/Smash + Carry/Total; updated repo structure and 'how it works'.
    - wiring.md: single radar placement (no V-formation / top radar), one LM358
    channel, single-channel passives, power rails.
    - bom.md: CDM324 ×1, LM358 ×1, single-channel passives, updated cost summary.
    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
2026-06-11 Rebuild on-device UI as LM1-style touch interface (v0.9)
    Replace the single ready/result/settings flow with a full touch UI modelled
    on the Shot Scope LM1, built on the existing TFT_eSPI layer (no LVGL):
    Main menu → Mode select → Session (Advanced / Large Digit) | Speed Training
    - Two themes (Black = white labels, Blue = cyan), toggled in Settings.
    - Advanced 3×2 grid + Large Digit single-metric layout; swipe ←/→ switches
    layout, swipe ↑/↓ cycles the focused metric.
    - LM1 club pill (replaces the circle) → tap opens a swipe-scrollable club
    picker; tap a metric cell (Advanced) jumps into Large Digit.
    - New ui_get_gesture() tap/swipe recogniser (classifies on release; deb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
    [config.h, main.cpp]
2026-06-11 Add custom test runner so `pio test -e native` works
    The native env uses `test_framework = custom` (the DSP smoke test has its own
    main() + CHECK macro rather than Unity), but PlatformIO ≥6 requires a
    CustomTestRunner class — without it `pio test -e native` aborts with
    "Could not find custom test runner".
    Add test/test_custom_runner.py: a minimal TestRunnerBase subclass that parses
    the program's `ok:` / `FAIL:` output lines into TestCases, so the run reports
    proper pass/fail counts (a suite with no registered cases is reported as
    SKIPPED even on a clean run). A non-zero program exit is still surfaced as a
    failure by the native output reader.
    Verified: clean run → "3 test cases ... PA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
2026-06-11 Add persisted shot history with on-device viewer
    Logs the last 50 shots (club, ball/club speed, carry, total) to a ring
    buffer persisted in NVS, and adds a Shot History entry to the main menu
    that opens a swipe-scrollable, newest-first table with a Clear action.
2026-06-11 Polish the touch UI: press feedback, unified headers, boot splash
    Every tappable control now flashes on touch (menu/mode/settings rows
    and the club pill), the four duplicated navy header blocks become one
    shared dark-card header with a themed accent underline, bottom nav bars
    get a filled dock treatment, menu rows gain chevron affordances, the
    history table is zebra-striped, and the device shows an OpenScope
    splash on boot.
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2026-07-02 Fix ESP32-S3 boot crash: force FSPI port in TFT_eSPI, drop PSRAM flags
    Without USE_FSPI_PORT, TFT_eSPI's S3 register path resolves SPI_PORT to
    FSPI (0) and IDF's REG_SPI_BASE(0) is literal address 0, so the first
    SET_BUS_WRITE_MODE in tft.init() stores to 0x10 → StoreProhibited panic
    on boot. USE_FSPI_PORT selects GPSPI2, matching the bus Arduino's
    SPIClass actually drives.
    Also drop qio_opi/BOARD_HAS_PSRAM: the delivered module reports no
    octal PSRAM (PSRAM ID read error at boot) and the firmware doesn't
    need it.
2026-07-02 Added the first versions of stl files
    Added the first test versions of stl files for manufacturing the shell.
    [BackShell-V2.STL, FrontShell-V2.STL]
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2026-07-03 Updated 3D files
    [BackShell-V2.STL, FrontShell-V2.STL]
2026-07-06 Replace touch UI with 3-button navigation (UP/DOWN/OK)
    The ILI9488 module in use has no XPT2046 touch controller fitted (raw
    SPI probing returned all zeros), so touch input is not an option on
    this hardware. Drop the touch layer entirely and drive the whole UI
    with three physical buttons instead:
    - UP (GPIO4) / DOWN (GPIO5): move the list highlight, change club
    (Advanced) or cycle the focused metric (Large Digit), adjust the
    calibration threshold; auto-repeat while held
    - OK (GPIO2, the old Power pin): select/confirm, hold 1.5 s to power
    off, press to wake from deep sleep
    Changes:
    - New buttons.h/cpp: debounced edge/repeat/long-press button driver
    - main.cpp: all UI loops rewritten a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
    [config.h, main.cpp]
2026-07-06 Fix instant re-wake from deep sleep; drive backlight from GPIO21
    Two power-off fixes found in hardware testing:
    - Deep sleep woke immediately: the digital-domain pull-ups power down
    in deep sleep, leaving the ext0 wake pin (OK, GPIO2) floating. Enable
    the RTC-domain pull-up before sleeping and hand the pad back to the
    digital GPIO matrix (rtc_gpio_deinit) on wake.
    - The backlight stayed lit through deep sleep because BL was wired
    straight to the always-on 3.3V rail. BL now moves to GPIO21 (free
    since touch was dropped, same header as the display pins): driven
    high in display_init, pulled low and gpio_hold-latched across deep
    sleep, released again on wake.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
    [config.h, main.cpp]
